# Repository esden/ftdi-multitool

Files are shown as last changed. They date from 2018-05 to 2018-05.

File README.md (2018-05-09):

This repository contains hardware designs for an FTDI FT232H based multi purpose tool.

The design goal is to make a very small FTDI breakout board that has a defined connector. That defined connector can receive a wide range of easy to design adapters. The adapters can then plug in into any variety of targets. The FTDI chip has a fairly wide range of protocols it supports, making it ideal for many applications.

## Protocol List
* TTY UART Serial (with or without hardware flow control)
* SPI using MPSSEngine
* I2C
* JTAG
* CPU Data Address

## Datasheet
For more information on the FTDI FT232 please refer to the chip's [datasheet](http://www.ftdichip.com/Support/Documents/DataSheets/ICs/DS_FT232H.pdf).

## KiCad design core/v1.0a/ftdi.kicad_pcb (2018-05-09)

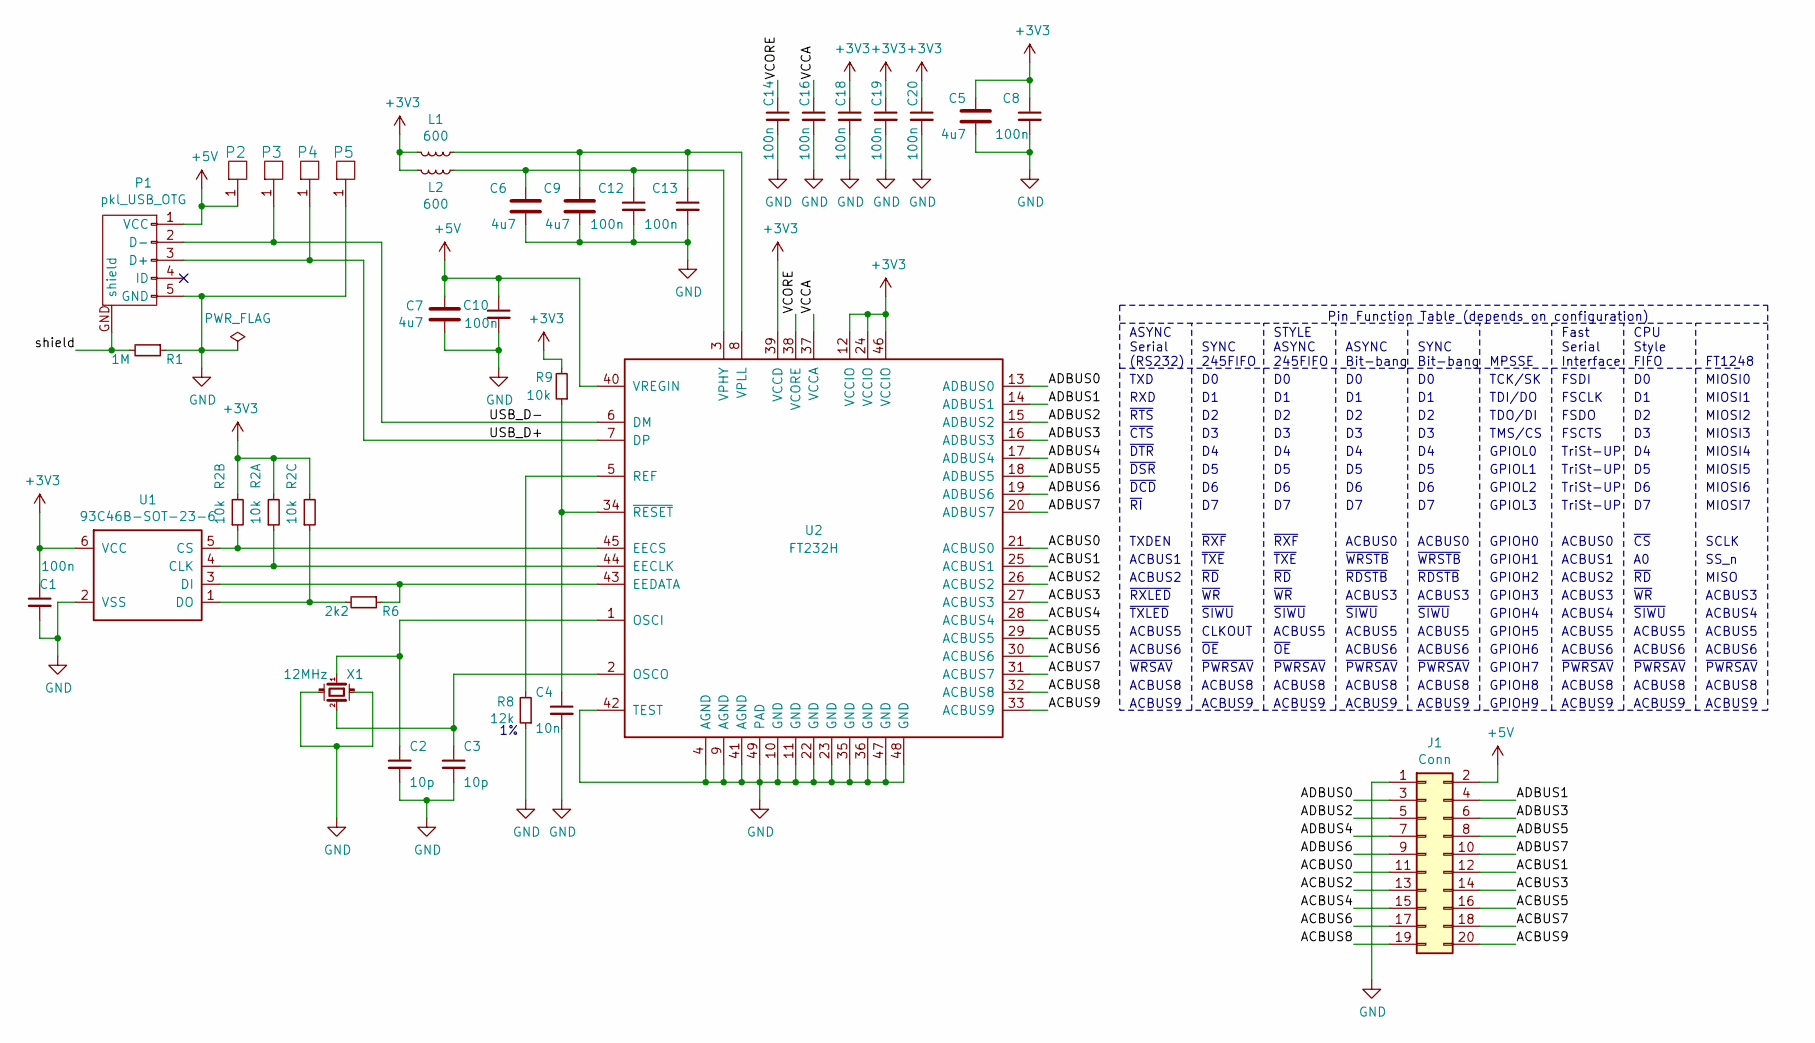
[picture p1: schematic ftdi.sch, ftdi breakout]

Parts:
C1, C8, C10, C12, C13, C14, C16, C18, C19, C20: 100n; C_0402
C2, C3: 10p; C_0402
C4: 10n; C_0402
C5, C6, C7, C9: 4u7; C_0603
J1: Conn; FTSH-EDGE-20pin
L1, L2: 600; L_0402
P1: pkl_USB_OTG; Connector_USB_Micro_B_SMD
P2, P3, P4, P5: UP; PAD_SMD_1x2.65
R1: 1M; R_0402
R2: 10k; R_Array_Convex_4x0402
R6: 2k2; R_0402
R8: 12k; R_0402
R9: 10k; R_0402
U1: 93C46B-SOT-23-6; SOT-23-6
U2: FT232H; QFN-48-1EP_8x8mm_Pitch0.5mm
X1: 12MHz; ABM8

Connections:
+3V3: C1.1, C5.1, C8.1, C18.1, C19.1, C20.1, L1.1, L2.1, R2.2, R2.4, R2.6, R9.2, U1.6 (VCC), U2.12 (VCCIO), U2.24 (VCCIO), U2.39 (VCCD), U2.46 (VCCIO)
+5V: C7.1, C10.1, J1.2, P1.1 (VCC), P2.1, U2.40 (VREGIN)
/ACBUS0: J1.11, U2.21 (ACBUS0)
/ACBUS1: J1.12, U2.25 (ACBUS1)
/ACBUS2: J1.13, U2.26 (ACBUS2)
/ACBUS3: J1.14, U2.27 (ACBUS3)
/ACBUS4: J1.15, U2.28 (ACBUS4)
/ACBUS5: J1.16, U2.29 (ACBUS5)
/ACBUS6: J1.17, U2.30 (ACBUS6)
/ACBUS7: J1.18, U2.31 (ACBUS7)
/ACBUS8: J1.19, U2.32 (ACBUS8)
/ACBUS9: J1.20, U2.33 (ACBUS9)
/ADBUS0: J1.3, U2.13 (ADBUS0)
/ADBUS1: J1.4, U2.14 (ADBUS1)
/ADBUS2: J1.5, U2.15 (ADBUS2)
/ADBUS3: J1.6, U2.16 (ADBUS3)
/ADBUS4: J1.7, U2.17 (ADBUS4)
/ADBUS5: J1.8, U2.18 (ADBUS5)
/ADBUS6: J1.9, U2.19 (ADBUS6)
/ADBUS7: J1.10, U2.20 (ADBUS7)
/USB_D+: P1.3 (D+), P4.1, U2.7 (DP)
/USB_D-: P1.2 (D-), P3.1, U2.6 (DM)
/VCCA: C16.1, U2.37 (VCCA)
/VCORE: C14.1, U2.38 (VCORE)
/shield: P1.GND (shield), R1.2
GND: C1.2, C2.2, C3.2, C4.2, C5.2, C6.2, C7.2, C8.2, C9.2, C10.2, C12.2, C13.2, C14.2, C16.2, C18.2, C19.2, C20.2, J1.1, P1.5 (GND), P5.1, R1.1, R8.1, U1.2 (VSS), U2.4 (AGND), U2.9 (AGND), U2.10 (GND), U2.11 (GND), U2.22 (GND), U2.23 (GND), U2.35 (GND), U2.36 (GND), U2.41 (AGND), U2.42 (TEST), U2.47 (GND), U2.48 (GND), U2.49 (PAD), X1.GND (case)
unnamed: C2.1, U2.1 (OSCI), X1.1
unnamed: C3.1, U2.2 (OSCO), X1.2
unnamed: C4.1, R9.1, U2.34 (~RESET)
unnamed: C6.1, C12.1, L2.2, U2.3 (VPHY)
unnamed: C9.1, C13.1, L1.2, U2.8 (VPLL)
unnamed: R2.1, U1.4 (CLK), U2.44 (EECLK)
unnamed: R2.3, U1.5 (CS), U2.45 (EECS)
unnamed: R2.5, R6.2, U1.1 (DO)
unnamed: R6.1, U1.3 (DI), U2.43 (EEDATA)
unnamed: R8.2, U2.5 (REF)

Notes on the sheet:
ASYNC Serial (RS232)
TXD
RXD
~RTS
~CTS
~DTR
~DSR
~RI
~DCD
TXDEN
ACBUS1
ACBUS2
~RXLED
~TXLED
ACBUS5
ACBUS6
~WRSAV
ACBUS8
ACBUS9
SYNC 245FIFO
~RXF
~TXE
~RD
~WR
~SIWU
CLKOUT
~OE
~PWRSAV
STYLE ASYNC 245FIFO
ASYNC Bit-bang
ACBUS0
~WRSTB
~RDSTB
ACBUS3
SYNC Bit-bang
MPSSE
TCK/SK
TDI/DO
TDO/DI
TMS/CS

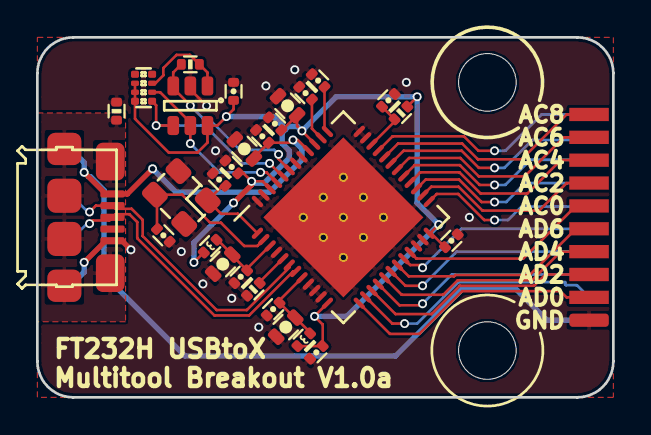
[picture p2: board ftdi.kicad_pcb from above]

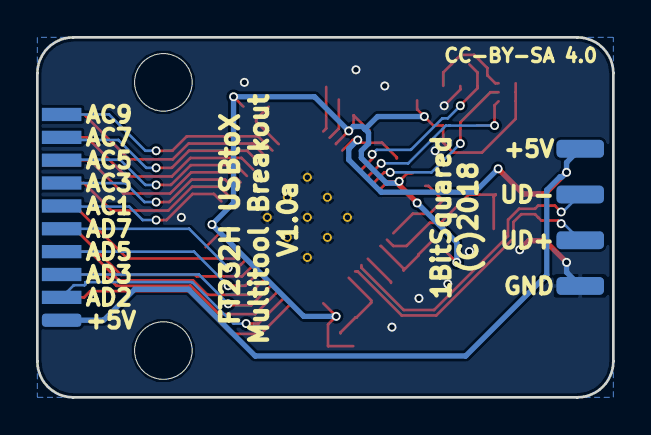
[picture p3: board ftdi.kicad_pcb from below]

Board: 2 copper layers, 32.0 x 20.0 mm, 33 parts (4 on the bottom side), 35 nets.

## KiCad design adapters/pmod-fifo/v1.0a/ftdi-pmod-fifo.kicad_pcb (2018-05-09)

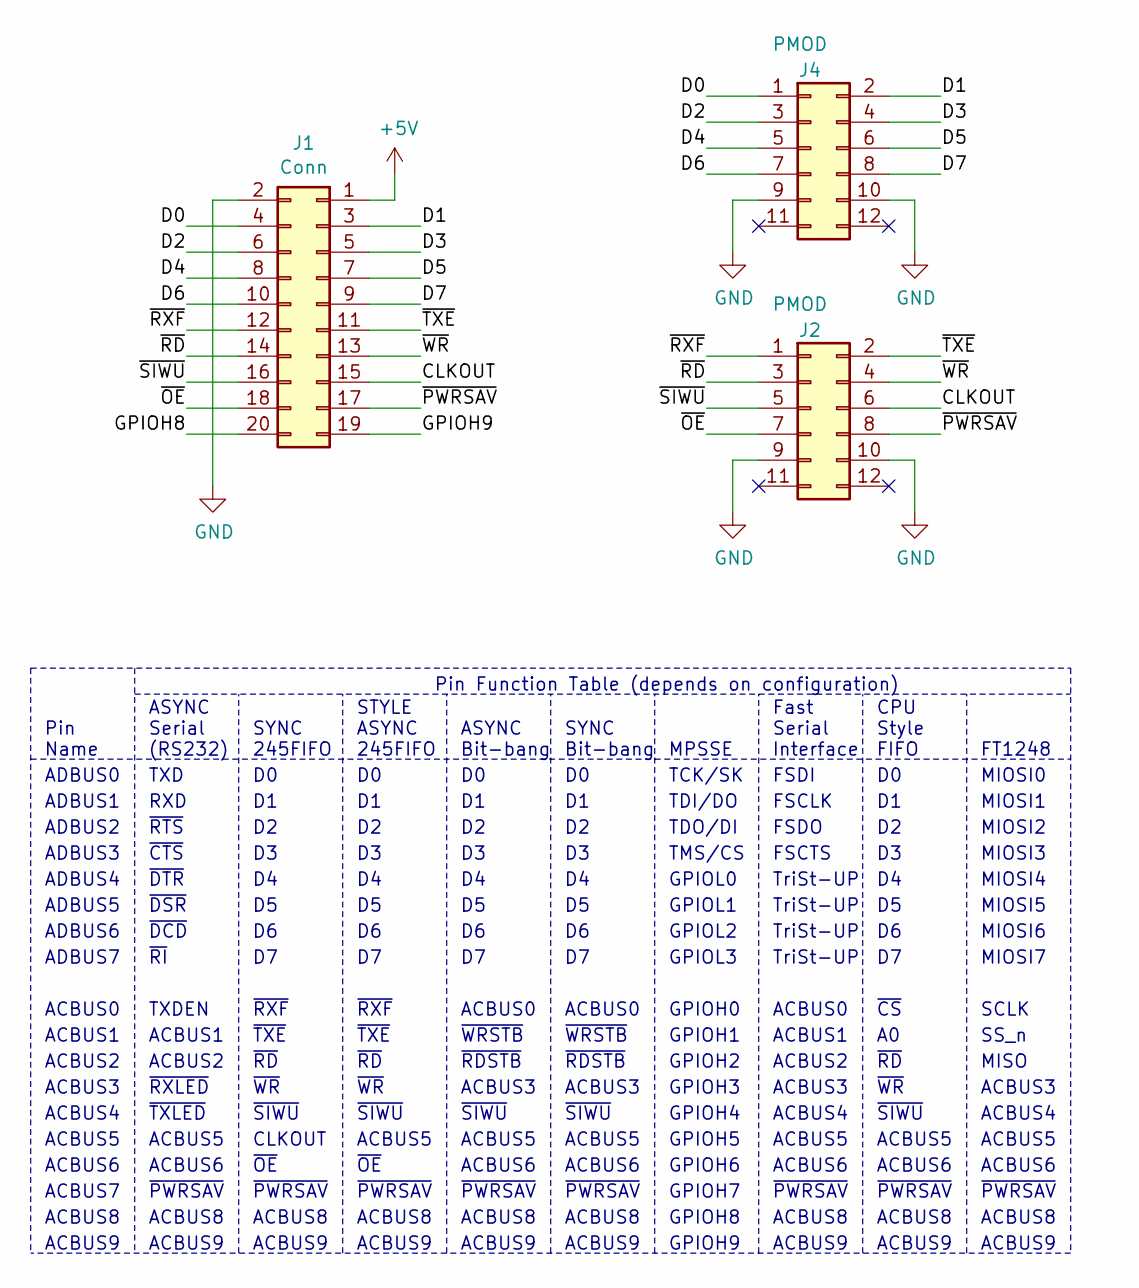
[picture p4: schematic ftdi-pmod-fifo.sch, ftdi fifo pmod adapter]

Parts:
J1: Conn; FTSH-EDGE-20pin
J2, J4: PMOD; PinHeader_2x06_P2.54mm_Horizontal

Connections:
+5V: J1.1
/CLKOUT: J1.15, J2.6
/D0: J1.4, J4.1
/D1: J1.3, J4.2
/D2: J1.6, J4.3
/D3: J1.5, J4.4
/D4: J1.8, J4.5
/D5: J1.7, J4.6
/D6: J1.10, J4.7
/D7: J1.9, J4.8
/GPIOH8: J1.20
/GPIOH9: J1.19
/~OE: J1.18, J2.7
/~PWRSAV: J1.17, J2.8
/~RD: J1.14, J2.3
/~RXF: J1.12, J2.1
/~SIWU: J1.16, J2.5
/~TXE: J1.11, J2.2
/~WR: J1.13, J2.4
GND: J1.2, J2.9, J2.10, J4.9, J4.10

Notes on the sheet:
STYLE ASYNC 245FIFO
~RXF
~TXE
~RD
~WR
~SIWU
ACBUS5
~OE
~PWRSAV
ACBUS8
ACBUS9
ASYNC Bit-bang
ACBUS0
~WRSTB
~RDSTB
ACBUS3
ACBUS6
SYNC Bit-bang
MPSSE
TCK/SK
TDI/DO
TDO/DI
TMS/CS
GPIOL0
GPIOL1
GPIOL2
GPIOL3
GPIOH0
GPIOH1
GPIOH2
GPIOH3
GPIOH4
GPIOH5
GPIOH6
GPIOH7
GPIOH8
GPIOH9
Fast Serial Interface
FSDI
FSCLK

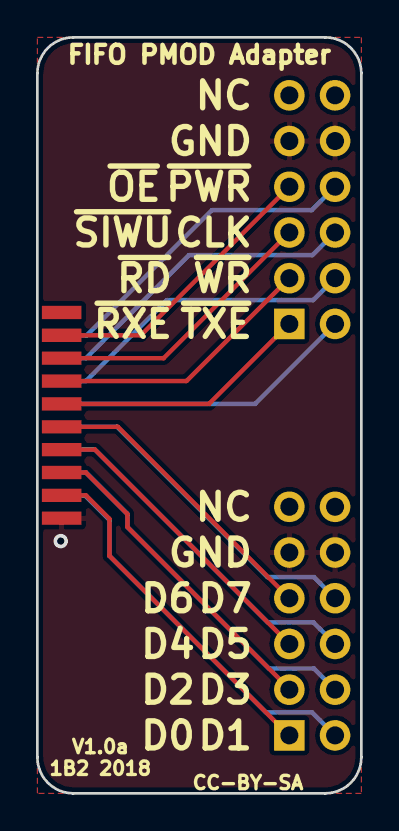
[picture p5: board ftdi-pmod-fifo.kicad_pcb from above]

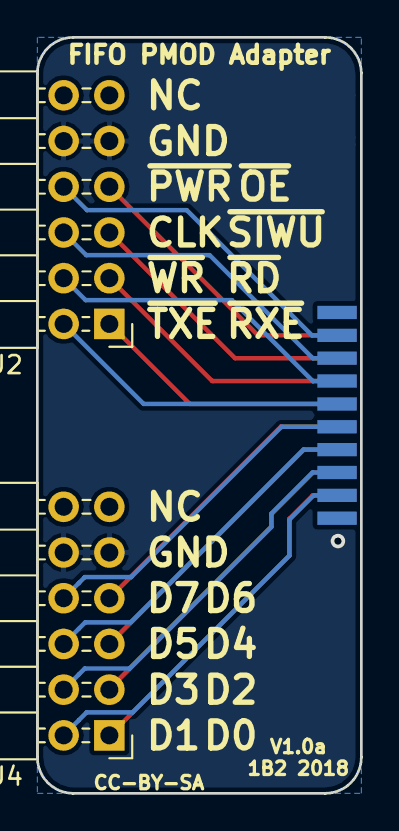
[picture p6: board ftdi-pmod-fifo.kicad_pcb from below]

Board: 2 copper layers, 18.0 x 42.0 mm, 3 parts (3 on the bottom side), 17 nets.

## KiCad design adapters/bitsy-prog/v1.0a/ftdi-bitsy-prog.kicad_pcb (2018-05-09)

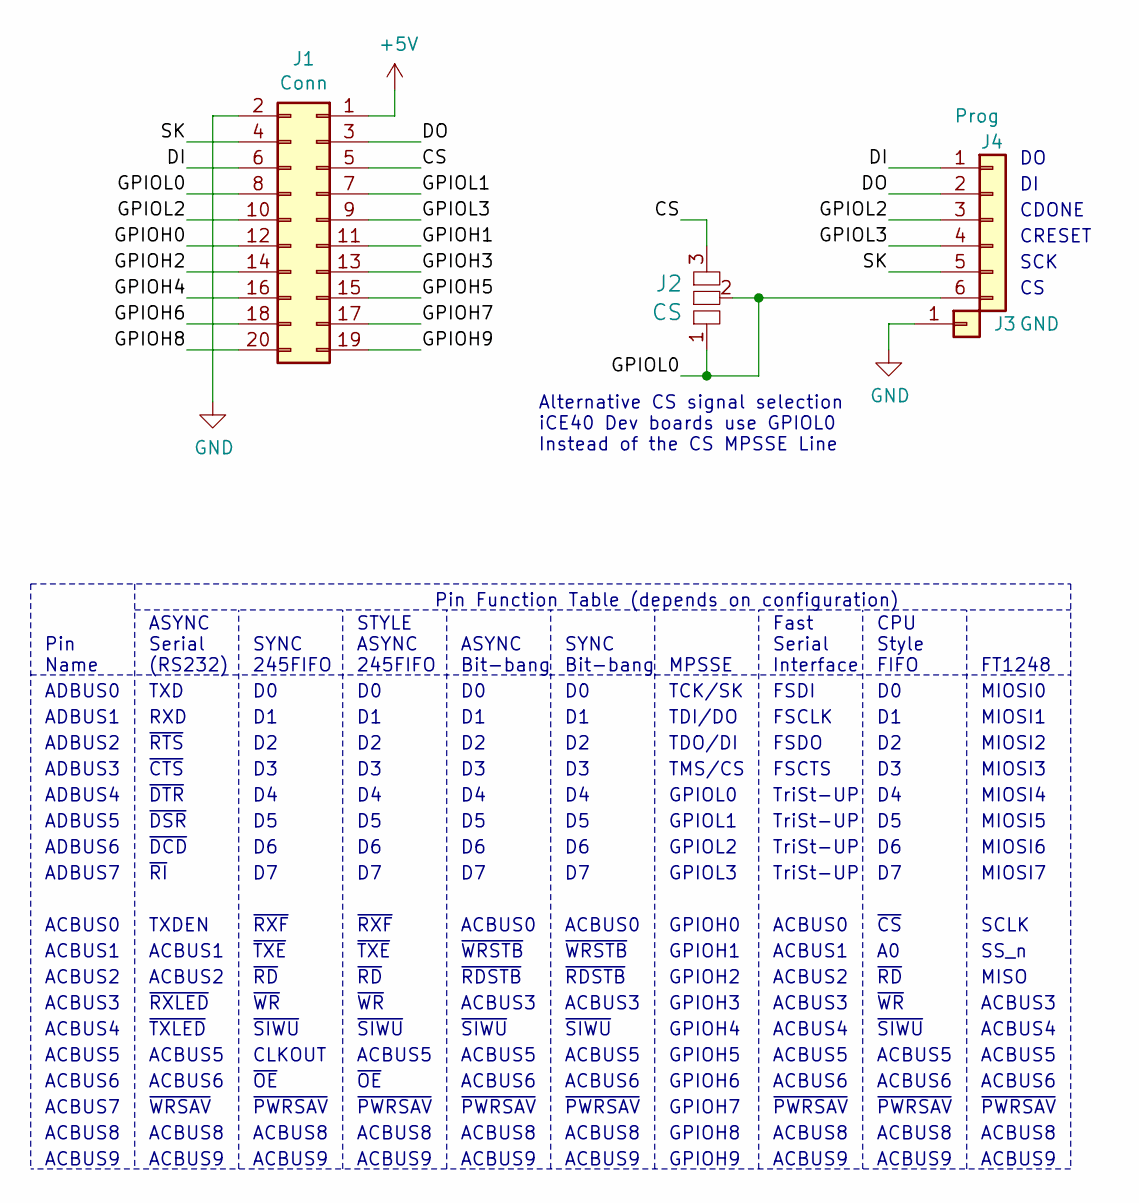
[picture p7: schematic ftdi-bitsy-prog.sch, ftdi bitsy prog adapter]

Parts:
J1: Conn; FTSH-EDGE-20pin
J2: CS; J_0602
J3: GND; PinSocket_1x01_P2.54mm_Vertical
J4: Prog; PinSocket_1x06_P2.54mm_Vertical

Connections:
+5V: J1.1
/CS: J1.5, J2.3
/DI: J1.6, J4.1
/DO: J1.3, J4.2
/GPIOH0: J1.12
/GPIOH1: J1.11
/GPIOH2: J1.14
/GPIOH3: J1.13
/GPIOH4: J1.16
/GPIOH5: J1.15
/GPIOH6: J1.18
/GPIOH7: J1.17
/GPIOH8: J1.20
/GPIOH9: J1.19
/GPIOL0: J1.8, J2.1, J2.2, J4.6
/GPIOL1: J1.7
/GPIOL2: J1.10, J4.3
/GPIOL3: J1.9, J4.4
/SK: J1.4, J4.5
GND: J1.2, J3.1

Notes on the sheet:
STYLE ASYNC 245FIFO
~RXF
~TXE
~RD
~WR
~SIWU
ACBUS5
~OE
~PWRSAV
ACBUS8
ACBUS9
ASYNC Bit-bang
ACBUS0
~WRSTB
~RDSTB
ACBUS3
ACBUS6
SYNC Bit-bang
MPSSE
TCK/SK
TDI/DO
TDO/DI
TMS/CS
GPIOL0
GPIOL1
GPIOL2
GPIOL3
GPIOH0
GPIOH1
GPIOH2
GPIOH3
GPIOH4
GPIOH5
GPIOH6
GPIOH7
GPIOH8
GPIOH9
Fast Serial Interface
FSDI
FSCLK

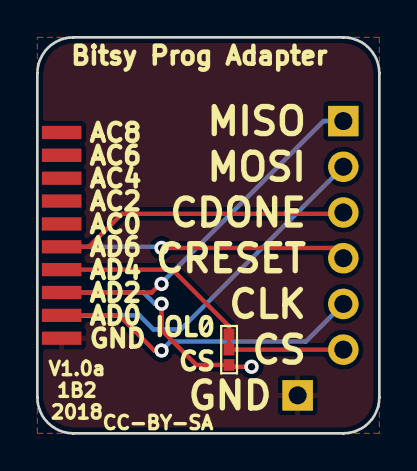
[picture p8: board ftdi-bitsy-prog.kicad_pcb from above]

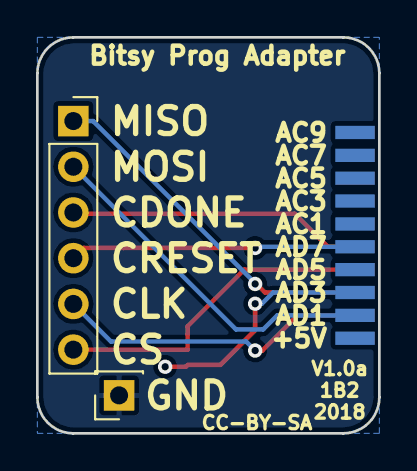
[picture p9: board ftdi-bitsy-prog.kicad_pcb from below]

Board: 2 copper layers, 19.0 x 22.0 mm, 4 parts (3 on the bottom side), 8 nets.

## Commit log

2018-05-09 Initial commit of the FTDI FT232 breakout.
    This breakout board is meant to be used as a multipurpose tool to work
    and interface with the icebreaker fpga boards and more.
    [ftdi.kicad_pcb, ftdi.sch]
2018-05-09 Changed the ftdi breakout design to use a 50mil header.
    This also decreases the width of the breakout, which will allow us to
    make standard complient 0.8" wide PMOD modules using the breakout board
    as a basis.
    [ftdi.kicad_pcb, ftdi.sch]
2018-05-09 Bumped the ftdi adapter to V1.0a. + minor improvements.
    [ftdi.kicad_pcb, ftdi.sch]
2018-05-09 Initial commit of the ftdi 100mil adapter.
    [ftdi-100mil.kicad_pcb, ftdi-100mil.sch]
2018-05-09 Added ftdi bitsy programmer adapter.
    [ftdi-bitsy-prog.kicad_pcb, ftdi-bitsy-prog.sch]
2018-05-09 Added ftdi spi pmod adapter.
    [ftdi-pmod-spi.kicad_pcb, ftdi-pmod-spi.sch]
2018-05-09 Added FTDI UART PMOD adapter.
    [ftdi-pmod-uart.kicad_pcb, ftdi-pmod-uart.sch]
2018-05-09 Updated the SPI PMOD adapter to a full PMOD interface.
    This setup allows the use of the adapter with INT and RST lines too.
    [ftdi-pmod-spi.kicad_pcb, ftdi-pmod-spi.sch]
2018-05-09 Corrected pmod UART pinout and added INT/RST pins.
    [ftdi-pmod-uart.kicad_pcb, ftdi-pmod-uart.sch]
2018-05-09 Fixed PMOD pinout on SPI adapter.
    [ftdi-pmod-spi.kicad_pcb, ftdi-pmod-spi.sch]
2018-05-09 A bunch of minor fixes.
    * PWRSAV instead of WRSAV in signal table.
    * 0.05 solder stop opening instead of 0.2
    * Better copper fill parameters.
    [ftdi-100mil.kicad_pcb, ftdi-100mil.sch, ftdi-bitsy-prog.kicad_pcb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]
2018-05-09 Added FTDI PMOD FIFO adapter.
    [ftdi-pmod-fifo.kicad_pcb, ftdi-pmod-fifo.sch]
2018-05-09 Corrected parameters for gerber export.
    [ftdi-100mil.kicad_pcb, ftdi-bitsy-prog.kicad_pcb, ftdi-pmod-fifo.kicad_pcb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]
2018-05-09 Added FTDI JTAG adapter.
    [ftdi-jtag.kicad_pcb, ftdi-jtag.sch, ftdi-pmod-uart.kicad_pcb]
2018-05-09 Improved legend of the FT232 USBtoX Multitool Breakout.
    [ftdi.kicad_pcb]
2018-05-09 Corrected fill on the UART PMOD adapter.
    [ftdi-pmod-uart.kicad_pcb]
2018-05-09 Removed paste from the edge connector pads.
    [ftdi.kicad_pcb]
2018-05-09 Placement plan adjustments.
    [ftdi.kicad_pcb]
2018-05-09 Added dimension drawing.
    [ftdi-100mil.kicad_pcb]
2018-05-09 Added some 3d models.
    [ftdi.kicad_pcb]

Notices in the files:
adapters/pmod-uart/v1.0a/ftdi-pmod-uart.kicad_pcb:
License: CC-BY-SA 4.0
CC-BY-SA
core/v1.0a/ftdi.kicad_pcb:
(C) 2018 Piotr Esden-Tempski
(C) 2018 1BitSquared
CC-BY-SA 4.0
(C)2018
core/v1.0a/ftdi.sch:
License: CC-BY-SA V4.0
